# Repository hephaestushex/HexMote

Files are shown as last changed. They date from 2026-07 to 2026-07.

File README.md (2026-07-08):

# HexMote
A wireless game controller with a built in IMU, allowing for motion controlled games. Uses the nRF52840 SuperMini and the ICM-20948 for motion controls.

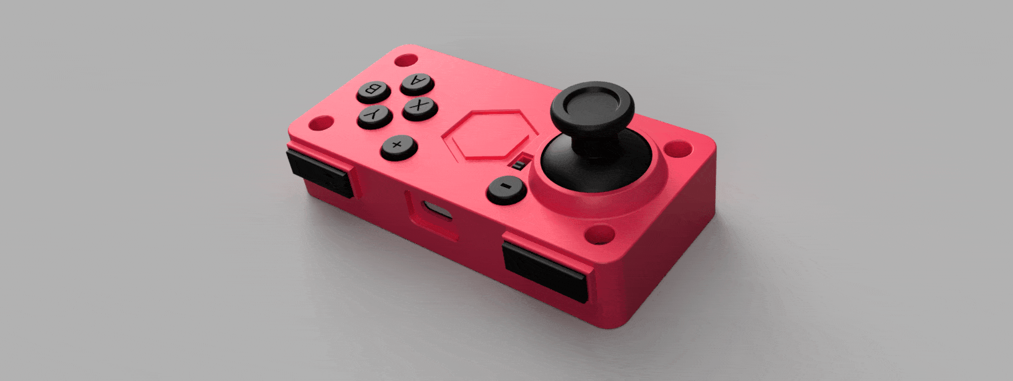
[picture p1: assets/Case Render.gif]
Animated Gif of HexMote, red


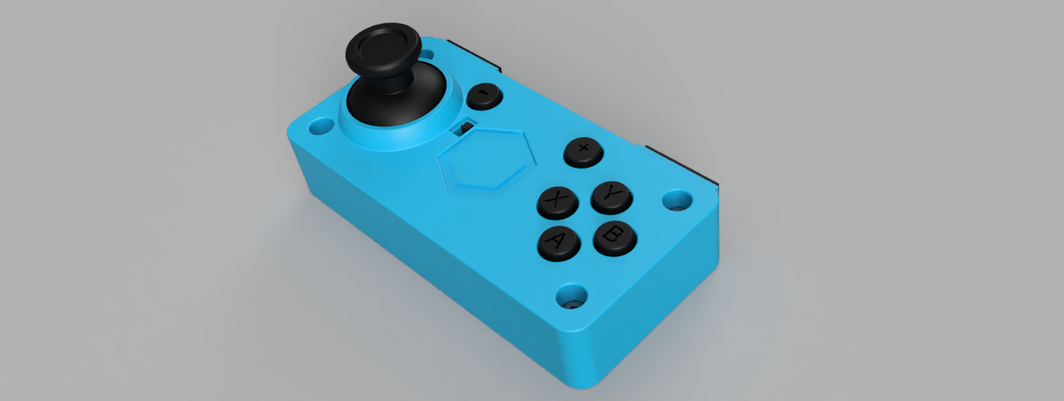
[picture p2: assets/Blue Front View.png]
Render of HexMote, Front, blue


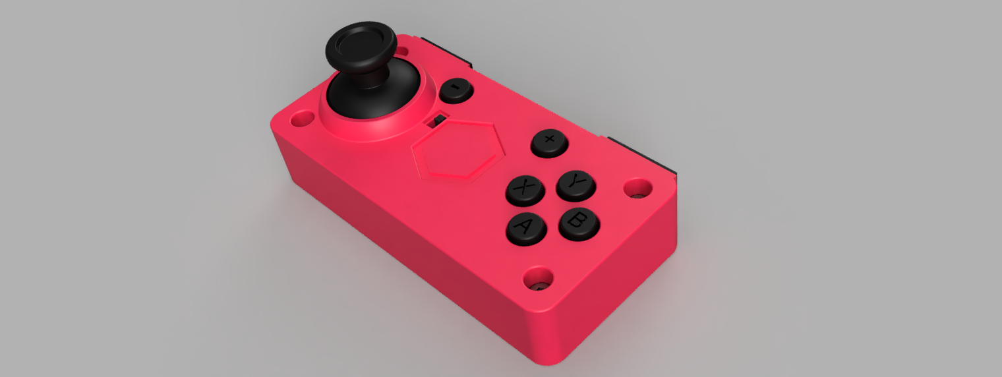
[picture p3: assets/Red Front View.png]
Render of HexMote, Front, red


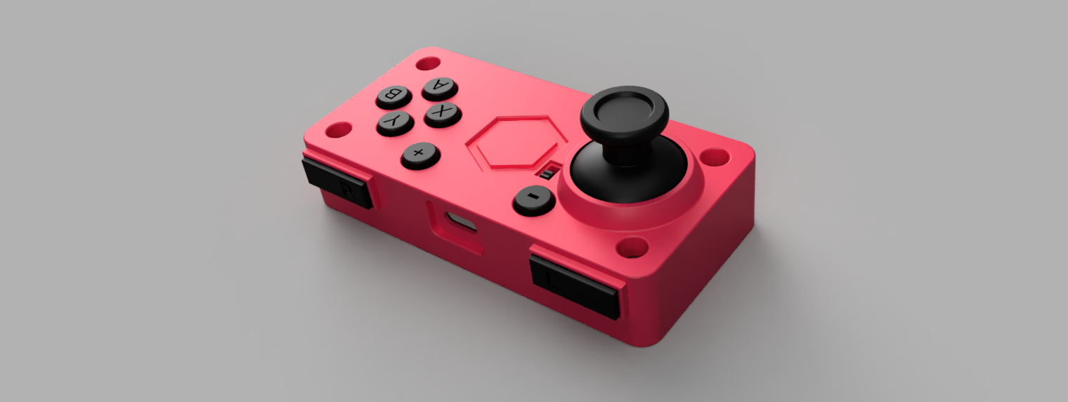
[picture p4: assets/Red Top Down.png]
Render of HexMote, Top Down, red


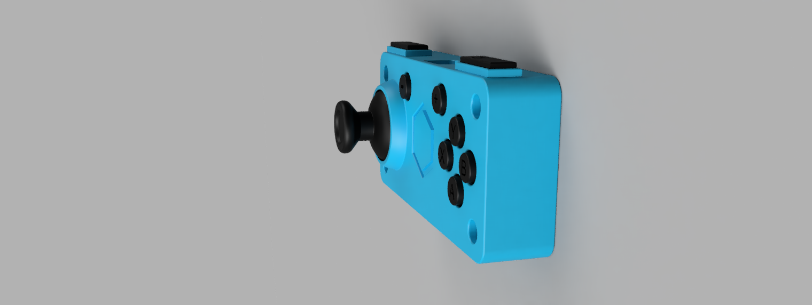
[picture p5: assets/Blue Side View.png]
Render of HexMote, Side, blue


# Inspiration
Recently, I started playing Mario Kart with my sister, but unfortunately for her, she's not too good at video games. The controllers I got, while having hall effect joysticks, lacked motion controls, so my poor sister struggled to steer with the tiny joystick, while turning the controller to no avail. So, I decided to make a Wii-mote-esque controller that would improve the usage while playing motion controlled games. That led birth to the HexMote, a wireless game controller built solely to improve less video-game inclined people.

# Schematic + PCB



Gerbers can be found in pcb/production



The schematic initially used a switch matrix, but falling back to direct pins proved better for pcb traces.







The PCB is 90x40mm, and has surfacemounted THT components through plugging holes with solder, and THT buttons and joysticks

# CAD

The case is split up into 3 parts, one of the top shell, one of the bottom shell, and one of the buttons all together





The PCB mounts on printed standoffs with heatset inserts placed within them, and the m3x6 screws directly into the top shell, through the pcb, and into the insert

# Firmware

The firmware for the hexmote is coded with Arduino, and uses several libraries to allow for BLE communication.

Unfortunately, there are no ways of directly parsing the gyro data within a game, so this requires a Cemuhook DSU script, which is included in the repo. Joystick and buttons work as normal however.

DISCLAIMER: As of right now, the code is AI generated and has not been tested on a physical product. Firmware will be updated and fixed once the HexMote has been built.

# BOM

| Item Name | Qty | Price (total) (USD) | Item link | Notes |
|---|---|---|---|---|
| nRF52840 ProMicro | 1 | $0.99 | [Link](https://www.aliexpress.com/item/1005007383270623.html) | Any nice!nano compatible board should work, check pcb footprint though |
| ICM-20948 Breakout Board | 1 | $4.20 | [Link](https://www.aliexpress.com/item/1005009307235033.html) | You can get a different IMU, but you have to code the sensor fusion code yourself |
| Right Angle Buttons | 2 | $0.99 | [Link](https://www.aliexpress.com/item/1005010093330224.html) | Make sure you get the right length (6x6x7) |
| JST-PH Connector | 1 | $0.99 | [Link](https://www.aliexpress.com/item/1005008970428474.html) | Make sure you get the right connector (right angle) |
| ALPS RKJXV Joystick | 1 | $0.99 | [Link](https://www.aliexpress.com/item/1005009112250803.html) | Make sure you get the PS4 style joystick |
| Soft Tactile Pushbutton | 8 | $0.99 | [Link](https://www.aliexpress.com/item/1005004588874318.html) | Do not substitute for regular clicky buttons, they are not the same footprint |
| M3x5x4 Inserts | 4 | $0.99 | [Link](https://www.aliexpress.com/item/1005011959188413.html) | Ships as 100 |
| M3x6 screws | 4 | $0.99 | [Link](https://www.aliexpress.com/item/32794842281.html) | Ships as 100 |
| 3.7v 500 mah lipo | 1 | $0.99 | [Link](https://www.aliexpress.com/item/1005001485127987) | Really anything works here so long as it meets the 5mm thick, up to 35mm by 80mm dimension requirement and has a jst ph 2.0 connector |
| PCB | 1 | $3.50 | [Link](https://github.com/hephaestushex/HexMote/blob/2a16dff57269423145945d0d09d0ee5307a6468b/pcb/production/hexmote_pcb.zip) | Link is to gerber files, JLC ships the total for 3.50 to Canada |
| Case | 1 | $1.00 | [Link](https://github.com/hephaestushex/HexMote/blob/d6d5b4342bca9d7315f2470e53cb6bb6a80dd431/cad/3d%20print.3mf) | Price differs based on filament. Bambu Lab PLA Matte is used here |
| **Total Price (USD):** | | **$16.62** | | |

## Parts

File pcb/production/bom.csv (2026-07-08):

Designator | Footprint | Quantity | Value | LCSC Part #
J2 | JST_PH_S2B-PH-K_1x02_P2.00mm_Horizontal | 1 | LiPo Cell
J3 | ICM-20498_Board | 1 | Conn_01x10_Pin
SW1, SW2, SW3, SW4, SW5, SW6 | Soft_Tactile_Button_6.00x4.5mm | 6 | SW_Push
SW10 | SW_Slide_SPDT_Straight_CK_OS102011MS2Q | 1 | SW_SPDT
SW7, SW8 | SW_Tactile_SPST_Angled_PTS645Vx83-2LFS | 2 | SW_Push
U2 | PS4_joystick | 1 | Joystick

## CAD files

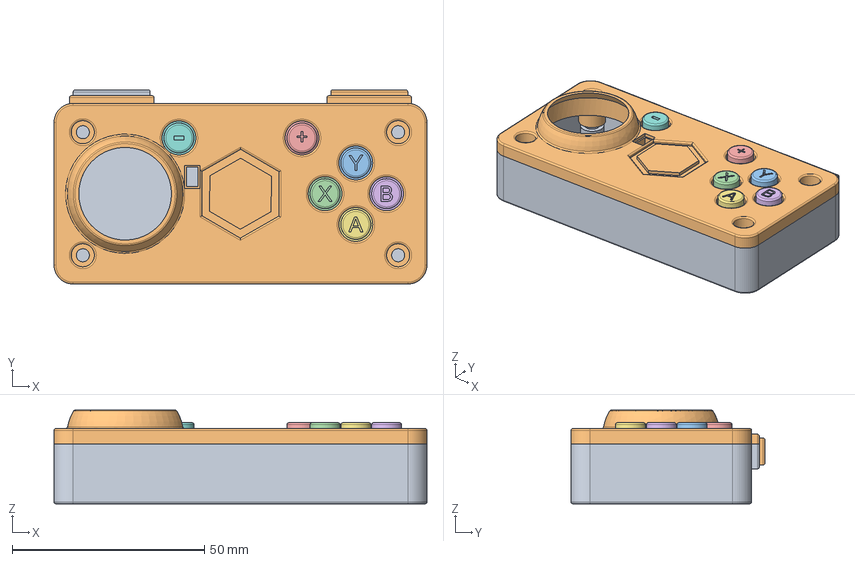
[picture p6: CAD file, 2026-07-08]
cad/Full Assembly.step
97.0 x 50.5 x 24.4 mm

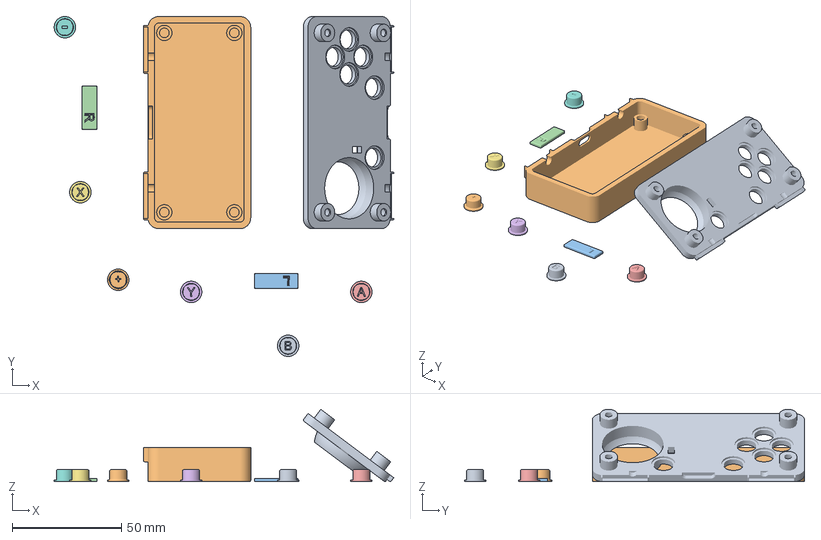
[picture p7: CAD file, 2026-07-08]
cad/3d print.3mf
155.3 x 155.4 x 33.1 mm
Top Shell.step
Bottom Shell.step
Case v36_7
Case v36_8
Case v36_5
Case v36_1
Case v36_2
Case v36_6
Case v36_4
Case v36_3

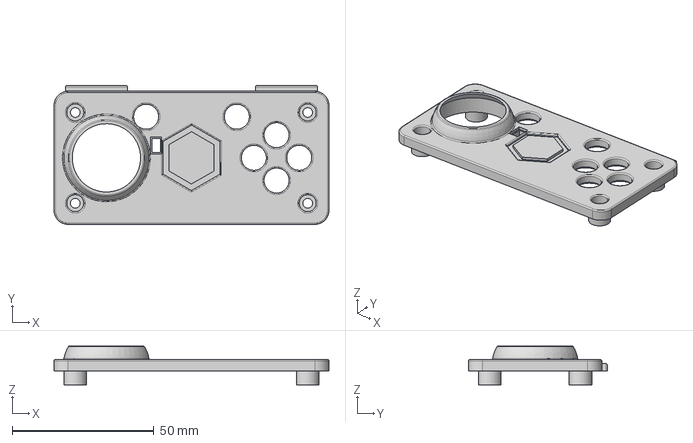
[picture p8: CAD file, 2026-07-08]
cad/Top Shell.step
97.0 x 49.0 x 13.8 mm

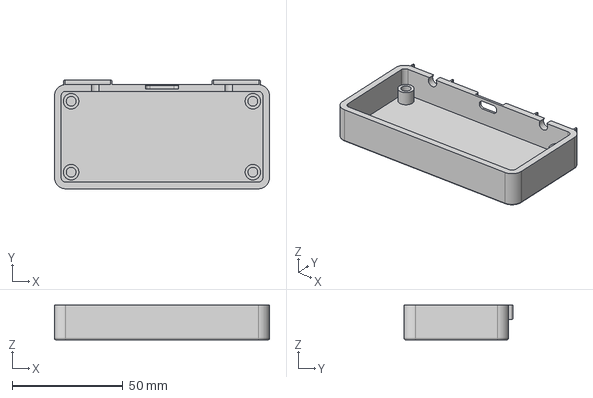
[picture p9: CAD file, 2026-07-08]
cad/Bottom Shell.step
97.0 x 49.0 x 15.6 mm

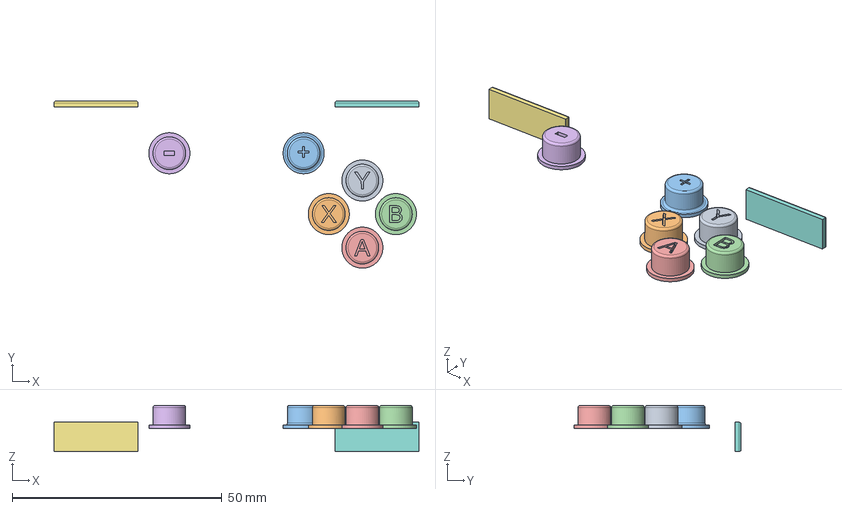
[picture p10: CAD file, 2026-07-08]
cad/Buttons.step
87.0 x 39.9 x 11.0 mm

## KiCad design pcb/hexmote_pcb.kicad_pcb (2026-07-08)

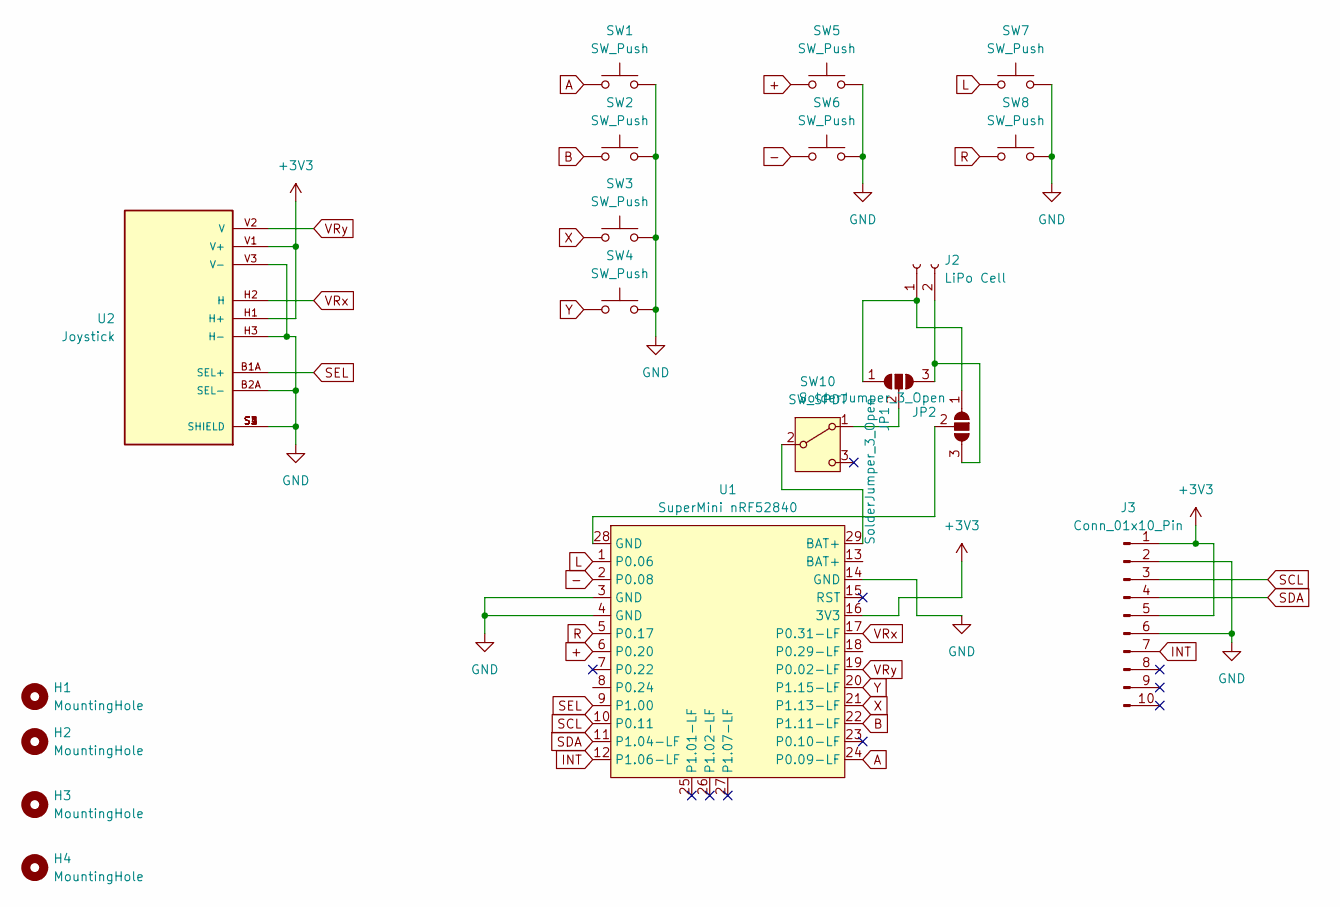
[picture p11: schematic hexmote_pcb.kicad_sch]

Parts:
H1, H2, H3, H4: MountingHole; MountingHole_3.2mm_M3
J2: LiPo Cell; JST_PH_S2B-PH-K_1x02_P2.00mm_Horizontal
J3: Conn_01x10_Pin; ICM-20498_Board
JP1, JP2: SolderJumper_3_Open; SolderJumper-3_P1.3mm_Open_Pad1.0x1.5mm_NumberLabels
SW1, SW2, SW3, SW4, SW5, SW6: SW_Push; Soft_Tactile_Button_6.00x4.5mm
SW7, SW8: SW_Push; SW_Tactile_SPST_Angled_PTS645Vx83-2LFS
SW10: SW_SPDT; SW_Slide_SPDT_Straight_CK_OS102011MS2Q
U1: SuperMini nRF52840; SuperMini NRF52840
U2: Joystick; PS4_joystick; PARTREV N/A

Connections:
+: SW5.1, U1.6 (P0.20)
+3V3: J3.1, J3.5, U1.16 (3V3), U2.H1 (H+), U2.V1 (V+)
-: SW6.1, U1.2 (P0.08)
A: SW1.1, U1.24 (P0.09-LF)
B: SW2.1, U1.22 (P1.11-LF)
GND: J3.2, J3.6, SW1.2, SW2.2, SW3.2, SW4.2, SW5.2, SW6.2, SW7.2, SW8.2, U1.3 (GND), U1.4 (GND), U1.14 (GND), U2.B2A (SEL-), U2.H3 (H-), U2.S1 (SHIELD), U2.S2 (SHIELD), U2.S3 (SHIELD), U2.S4 (SHIELD), U2.V3 (V-)
INT: J3.7, U1.12 (P1.06-LF)
L: SW7.1, U1.1 (P0.06)
unnamed: J2.1, JP1.1 (A), JP2.1 (A)
unnamed: J2.2, JP1.3 (B), JP2.3 (B)
unnamed: JP1.2 (C), SW10.1 (A)
unnamed: JP2.2 (C), U1.28 (GND)
unnamed: SW10.2 (B), U1.29 (BAT+)
R: SW8.1, U1.5 (P0.17)
SCL: J3.3, U1.10 (P0.11)
SDA: J3.4, U1.11 (P1.04-LF)
SEL: U1.9 (P1.00), U2.B1A (SEL+)
VRx: U1.17 (P0.31-LF), U2.H2 (H)
VRy: U1.19 (P0.02-LF), U2.V2 (V)
X: SW3.1, U1.21 (P1.13-LF)
Y: SW4.1, U1.20 (P1.15-LF)

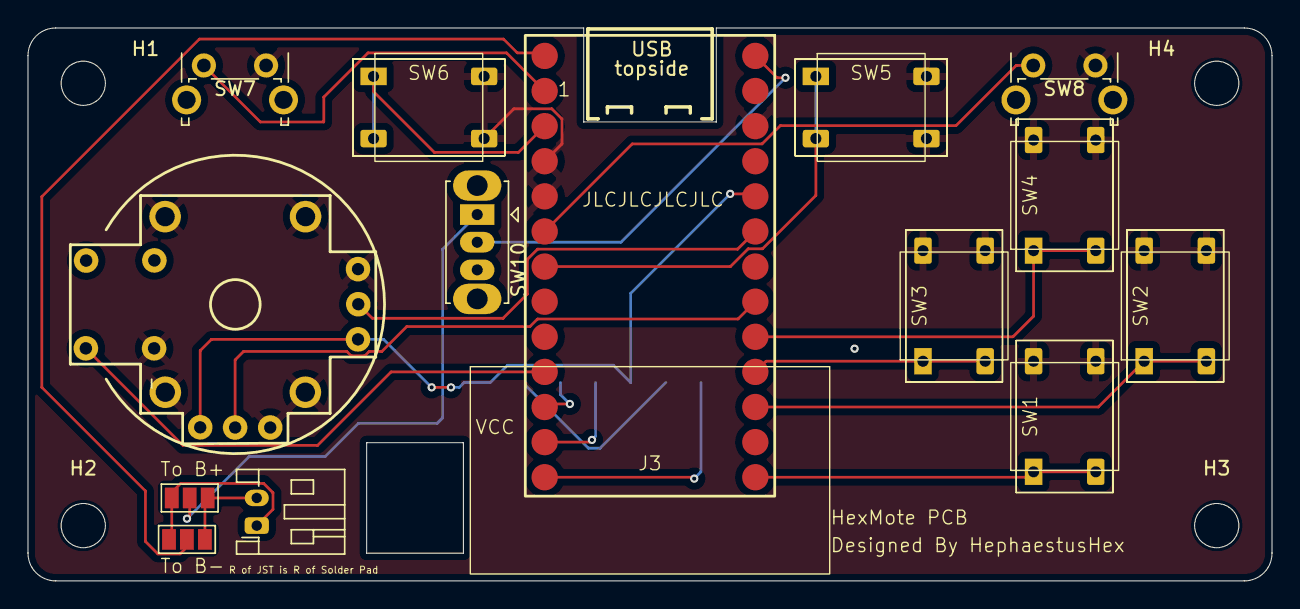
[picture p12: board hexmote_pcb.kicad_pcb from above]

Board: 2 copper layers, 90.0 x 40.0 mm, 19 parts (0 on the bottom side), 21 nets.

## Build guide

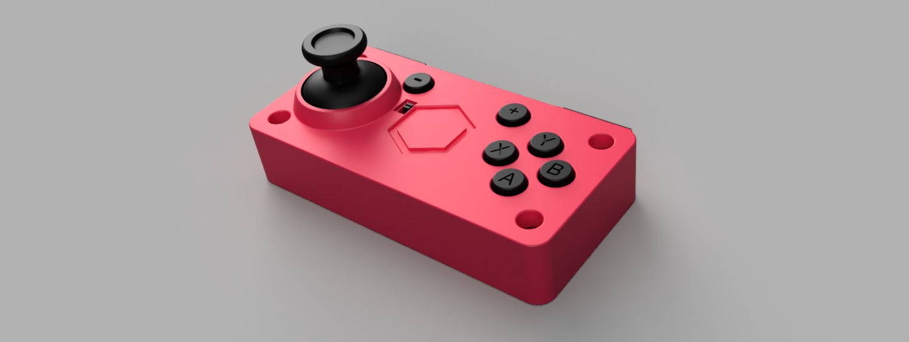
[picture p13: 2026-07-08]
assets/Case_(Assembly)_2026-Jul-08_06-05-27PM-000_CustomizedView10271644335_zip/frame.3.png

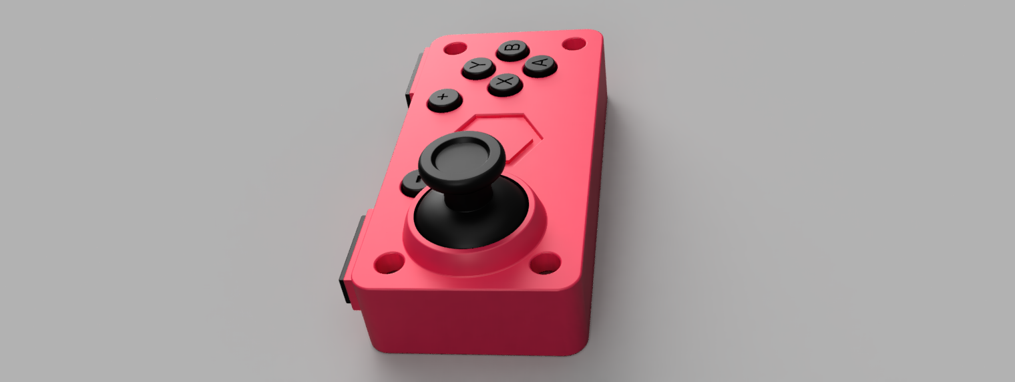
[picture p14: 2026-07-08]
assets/Case_(Assembly)_2026-Jul-08_06-05-27PM-000_CustomizedView10271644335_zip/frame.5.png

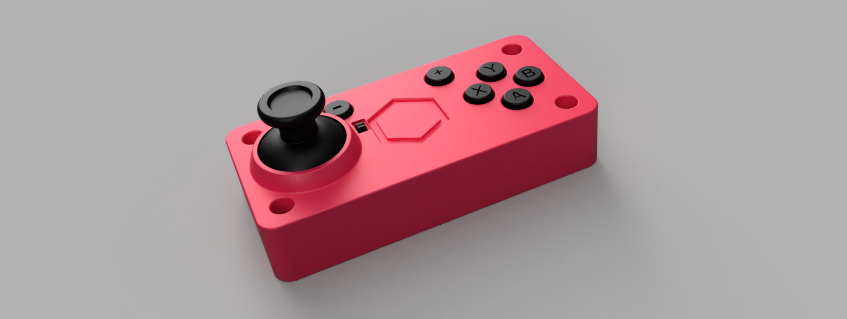
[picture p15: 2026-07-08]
assets/Case_(Assembly)_2026-Jul-08_06-05-27PM-000_CustomizedView10271644335_zip/frame.4.png

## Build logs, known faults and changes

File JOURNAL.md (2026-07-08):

# JOURNAL

# Total time: 14h

# July 6th

*Note: I was too locked in to take screenshots, but I did record through lapse*

[Recording 1](https://lapse.hackclub.com/timelapse/f-8UHHHKltJs)
[Recording 2](https://lapse.hackclub.com/timelapse/fGfNaLuvpSXH)

## 6h

I had a vague idea of what I was building before I went into this, so here's a quick explanation:

 - Wireless Game Controller with Motion Controls
 - uses nRF52840 for power efficient BLE (seeed studio xiao nrf52840 board)
 - Uses 18650 cell
 - has low profile joystick, 4 a/b/x/y buttons, +/-, l/r
 - has an IMU for motion controls (generic arduino module?)

From here, I just went on a long speedrun of pcb design. It mostly went as you expected (place symbols, wire it up, assign footprints, arrange, wire, done!), but I ran into several hurdles along the way. I'll explain each hurdle in detail

### Parts Selection

There wasn't enough pins on the XIAO, so I opted for the nRF52840 SuperMini board. It's a clone of the nice!nano, but its readily available on aliexpress

The Wii uses an IR sensor for detecting heading, so I needed a board with heading detection, so no mpu6050. I found the ICM-20948, which has 9 DOF (3x accelerometer, 3x gyro, 3x magnetometer)

The 18650 is too big and would make the overall controller large and heavy, so I switched to a 3.7v LiPo Battery.

None of the low-profile joysticks seem to have a basic pinout on aliexpress, so I opted for a ALPS Joystick that you would find in a PS4/XBOX controller. It should be smaller than the arduino joystick modules. At least it will be mounted directly to the pcb to save on vertical clearance. 

The rest of the parts selection was easy, simply searching on aliexpress for something that'll work.

### PCB Footprints/Schematics

There aren't any readily available footprints/schematics for the joystick, so I had to scour the internet for one that'll work with the joystick. I found this module from [github](https://github.com/little-scale/PS4_joystick_footprint), and the person also made it in real life so I trusted it would fit.





I didn't bother with finding footprints for the squishy buttons (IMO better than clicky for game controllers), so I made a footprint based on the aliexpress diagram.



As for the IMU, I had to create a footprint to ensure my parts won't intrude on it. I also realized I was looking at another module halfway into designing the PCB.



### IMU Mounting

I can't place the imu off to the side for two reasons. A, it would take too much room, and B, it wouldn't record motions properly

I chose to mount it on the back to solve these problems, but the long headers would clash with the MCU. I know of a method to solder tht boards smd style, by plugging the holes with solder, so I changed the THT pads to SMD pads for it.

I also found out that the MCU might mess with the magnetometer, so I placed it down the PCB to avoid it



### To make a matrix, or not to make a matrix, that is the question

I initially used a switch matrix to save on pins, but the diodes couldn't be placed nicely without taking more space. The wiring turned out horrible with way too much vias. It could also be because I didn't route traces properly, but direct pins plus a ground plane made the wiring way cleaner.



### Layout

The PCB layout was tricky, as I was rusty, plus there's a lot more components. In the end, I managed to get it squished under 90mm by 40mm, so $2 dollar pcbs for JLC!

### nRF52840 internal multiplexer my goat

I would have been fried if the nRF52840 kept its pins static. Luckily, almost every pin can be used for everything, so I could select pins based on which was closer and cleaner.

### Conclusion

Well I finished the PCB, so heres a few pictures of it.







Oh I did run into a couple of DRC errors. It had to do with the ground plane, but all I had to do is move a couple of traces around.

Also Claude is the GOAT of AI, it can actually do stuff without hallucinating (chatgpt), or run into safety filter every 5 seconds (gemini), and it even has a better toolbox! Would not have done it this fast without claude.

# July 7th-8th (not really, i just pulled an all nighter)
## 7h (this much screen time can't be good on my eyes)

[Timelapse](https://lapse.hackclub.com/timelapse/uQqbto0yiFiv) please look at this as I was too locked in to take screenshots apart for a few.

So I didn't do any CAD yet, so I cracked down on it and started in the evening, and stayed up until 4:30? (its 4:20 as of writing this)

First issue was I was rusty, so apart of creating the base and sticking a couple of pegs on it, I was stuck on figuring out how to create the holes properly



I ran into a lot of unconstrained lines, but after a while I gave up, considering it doesn't necessarily break anything at this scale (note to self: take an actual CAD course). That doesn't mean I didn't try, I just didn't try too hard to fix the annoying constraints (text boxes) 

Another annoying thing is finding CAD reliably without making 5000 accounts. I did make a handheld a year back, so I lowkey just stole the cad files from that since I couldn't find it today. It's also today I resigned myself to the fact that I will not get this in time for Outpost (sadge) but redesigning it to house more expensive parts that might arrive on time didn't make sense. Plus no one sells lipos and nice!nanos for a decent rate in Canada.

It also occured to me that I didn't account for lipos being wired wrong, so I added solder pads to fix that. It did appear that most had + on the right, but I figured this would be better. That also led into a rabbit hole of finding lipos that would work, but after chatting with Claude (goat btw), I figured anything about 500mah that was legit would work. I also made sure to design the case to fit the lipo (anything 5mm thick, within 40x90mm). In the end, I just slapped some aliexpress links there that would work.

CAD was not fun, so here are some highlights (or lack thereof):

### Creating holes

I had no idea how to make the holes in the right place, so I bounced back and forth between the PCB and Fusion measuring out dimensions and seeing if they worked. I realized too late I can import an stl into a part studio. After a lot of trial and error, I created the holes in the right place for the shoulder buttons and the USB-C slot. This time, I actually spent time and made the hole look pretty, and I think it was worth it!



### Create elevated portion for Joystick

So like I said, I don't really know CAD too well, just enough to trudge along. So when it came time for me to do something other than a sketch and extrude, I blanked out. After some searching up, I learned how to create an offset plane. From there, it wasn't too bad, just a matter of creating curves and revolving them.



### How to fit everything together without making it too thick

So i really should have went into this with a written out plan. I figured I could have two circles of inserts, one for the pcb, and one for the case, but that was too thick, so I reduced it to one by sandwiching the whole case+pcb under one screw and insert.



### Buttons

This actually wasn't hard as it was tedious, creating circles and making sure the buttons remained separate from the case, which happened a few times





So that's an issue, but I figured that it shouldn't matter too much, as no one is necessarily needing to press - while controlling the joystick in the horizontal position, and in the vertical position, it can be held easily with the right hand or dual handed like a sword.

### Text
Text is a pain to constrain, I'll leave it at that. I didn't even bother doing it properly

### Shoulder Buttons

Initially, I planned to leave the shoulder buttons alone, but I ended up designing them



So I decided to design shoulder buttons for two reasons:
-  They're probably annoying to reach and press
-  they kind of look like nipples



I had to make sure it doesn't look too bad, so I designed the guard rails as well.

### Rendering
I wanted to render it, but apparently, being linked forces all of the objects to stay the same colour, but fusion removed the break link feature for some reason, causing me to crash out for 10 minutes. (claude my goat for helping me break the link through another menu). Eventually, I got it, set it to totally not important colours, and rendered them!

Red Top Down
Red Front View
Blue Side View
Blue Front View

### Conclusion

It is now 5 AM, and I have been up for nearly 23 hours. I doubt I can work on firmware now, so I'll come back to it tomorrow. No actually today.

Overall a pretty productive day(s) I would say.

# July 8th (for real this time)

## 1h

[Lapse](https://lapse.hackclub.com/timelapse/Px4isJaHPv2T)

So in my sleep deprivedness, I forgot to make a hole for the switch, which I promptly did, followed by the restructuring of every CAD file + render. I also made a nice gif for rotating the HexMote around.

As for the firmware, it turns out I should have done more research, as BLE doesn't natively send gyro data, so the nRF52840 doesn't really work for this. However, there is a fix, by sending raw gyro data over and using a DSU server for gyro data, which works for the emulators I need anyway (raw ble doesn't really work). Claude was surprisingly helpful, and made the code that works (with no hardware errors at least) on the second try.

From there, all I'm doing is cleaning this project up and submitting it, which shouldn't take too long as I have been doing it along the way

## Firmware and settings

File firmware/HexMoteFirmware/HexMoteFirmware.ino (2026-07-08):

/*
 * HexMote Firmware -- v0.4
 * SuperMini nRF52840 + ICM-20948 + ALPS joystick
 *
 * v0.4 switches to the official Adafruit BLEHidGamepad class instead of a
 * hand-rolled BLEHidGeneric descriptor -- caught real compile errors in the
 * v0.3 approach (setReportLen/setReportDescriptor signatures were wrong).
 * This is now built on the library's own tested gamepad implementation.
 *
 * v0.3 added Serial debug output (gated by DEBUG_SERIAL below) so you can
 * verify buttons, joystick, and IMU are alive over USB before trusting the
 * BLE side. Flip DEBUG_SERIAL to 0 once everything checks out.
 *
 * Architecture (locked in):
 *   - Standard BLE HID gamepad (buttons + stick) -> works natively in Steam
 *     Input, Windows, Linux, anywhere -- zero extra software required.
 *   - Separate custom BLE GATT service streaming raw accel+gyro -> read by
 *     your Steam Deck DSU companion app, which relays it to Dolphin/Cemu/
 *     Yuzu as a standard DSU (cemuhook) motion source.
 *   - Steam Input gyro (native, non-emulator games) is NOT covered by this
 *     path -- that's a separate DS4-identity-spoof problem, not built here.
 *
 * Pin mapping (from hexmote_pcb.kicad_sch):
 *   A=P0.09  B=P1.11  X=P1.13  Y=P1.15
 *   L=P0.06  R=P0.17  +=P0.20  -=P0.08
 *   Joystick click (SEL) = P1.00
 *   Joystick X (AIN7) = P0.31   Joystick Y (AIN0) = P0.02
 *   I2C: SCL=P0.11  SDA=P1.04  IMU INT=P1.06 (unused, poll-only for now)
 *
 * Charging: fully hardware (onboard SuperMini charge IC + SW10 power
 * switch). No firmware involvement.
 *
 * !! IMPORTANT: the motion GATT UUIDs and 12-byte payload layout below are
 * placeholders I defined myself. I don't have visibility into what your
 * specific Steam Deck DSU companion app expects on the BLE side -- you'll
 * need to check its docs/source and either match its expected UUID/format,
 * or adjust the app's parsing to match what's below. Flagging this clearly
 * so it's not a silent assumption.
 *
 * Compile-UNTESTED (no nRF52 toolchain in this sandbox). Pin assignments
 * verified against the schematic; BLE/IMU boilerplate is standard-pattern
 * but give it a real smoke test before trusting it.
 */

#include <bluefruit.h>
#include <Wire.h>
#include <nrf_gpio.h>
#include <nrf_saadc.h>

// ---------------- Debug scaffolding ----------------
// Flip to 0 once everything's verified -- Serial prints cost a little loop
// time and there's no reason to keep them running once BLE is trusted.
#define DEBUG_SERIAL 1

#if DEBUG_SERIAL
  #define DBG_BEGIN(baud)   Serial.begin(baud)
  #define DBG_PRINT(...)    Serial.print(__VA_ARGS__)
  #define DBG_PRINTLN(...)  Serial.println(__VA_ARGS__)
#else
  #define DBG_BEGIN(baud)
  #define DBG_PRINT(...)
  #define DBG_PRINTLN(...)
#endif

// ---------------- Pin definitions (raw GPIO numbers) ----------------
#define PIN_A     NRF_GPIO_PIN_MAP(0, 9)
#define PIN_B     NRF_GPIO_PIN_MAP(1, 11)
#define PIN_X     NRF_GPIO_PIN_MAP(1, 13)
#define PIN_Y     NRF_GPIO_PIN_MAP(1, 15)
#define PIN_L     NRF_GPIO_PIN_MAP(0, 6)
#define PIN_R     NRF_GPIO_PIN_MAP(0, 17)
#define PIN_PLUS  NRF_GPIO_PIN_MAP(0, 20)
#define PIN_MINUS NRF_GPIO_PIN_MAP(0, 8)
#define PIN_SEL   NRF_GPIO_PIN_MAP(1, 0)   // joystick click

#define PIN_SDA   NRF_GPIO_PIN_MAP(1, 4)
#define PIN_SCL   NRF_GPIO_PIN_MAP(0, 11)

#define AIN_JOY_X  7   // P0.31
#define AIN_JOY_Y  0   // P0.02

// ---------------- ICM-20948 register map (minimal subset) ----------------
#define ICM_ADDR        0x69   // change to 0x68 if your breakout pulls AD0 low
#define REG_BANK_SEL    0x7F
#define B0_WHO_AM_I     0x00
#define B0_PWR_MGMT_1   0x06
#define B0_ACCEL_XOUT_H 0x2D
#define B0_GYRO_XOUT_H  0x33
#define B2_GYRO_CFG_1   0x01
#define B2_ACCEL_CFG    0x14

bool icmSelectBank(uint8_t bank) {
  Wire.beginTransmission(ICM_ADDR);
  Wire.write(REG_BANK_SEL);
  Wire.write(bank << 4);
  return Wire.endTransmission() == 0;
}

bool icmWriteReg(uint8_t bank, uint8_t reg, uint8_t val) {
  icmSelectBank(bank);
  Wire.beginTransmission(ICM_ADDR);
  Wire.write(reg);
  Wire.write(val);
  return Wire.endTransmission() == 0;
}

bool icmReadRegs(uint8_t bank, uint8_t reg, uint8_t *buf, uint8_t len) {
  icmSelectBank(bank);
  Wire.beginTransmission(ICM_ADDR);
  Wire.write(reg);
  if (Wire.endTransmission(false) != 0) return false;
  Wire.requestFrom(ICM_ADDR, (int)len);
  for (uint8_t i = 0; i < len && Wire.available(); i++) buf[i] = Wire.read();
  return true;
}

uint8_t icmLastWhoAmI = 0; // stashed for debug printing after icmInit()

bool icmInit() {
  uint8_t who = 0;
  icmReadRegs(0, B0_WHO_AM_I, &who, 1);
  icmLastWhoAmI = who;
  if (who != 0xEA) return false; // wrong address or not detected -- check ICM_ADDR/wiring

  icmWriteReg(0, B0_PWR_MGMT_1, 0x01);   // wake, auto clock select
  delay(10);
  icmWriteReg(2, B2_GYRO_CFG_1, 0x00);   // +/-250 dps, no DLPF (default)
  icmWriteReg(2, B2_ACCEL_CFG, 0x00);    // +/-2g, no DLPF (default)
  return true;
}

void icmReadMotion(int16_t &ax, int16_t &ay, int16_t &az,
                    int16_t &gx, int16_t &gy, int16_t &gz) {
  uint8_t raw[6];
  icmReadRegs(0, B0_ACCEL_XOUT_H, raw, 6);
  ax = (int16_t)((raw[0] << 8) | raw[1]);
  ay = (int16_t)((raw[2] << 8) | raw[3]);
  az = (int16_t)((raw[4] << 8) | raw[5]);

  icmReadRegs(0, B0_GYRO_XOUT_H, raw, 6);
  gx = (int16_t)((raw[0] << 8) | raw[1]);
  gy = (int16_t)((raw[2] << 8) | raw[3]);
  gz = (int16_t)((raw[4] << 8) | raw[5]);
}

// ---------------- Minimal blocking SAADC read ----------------
uint16_t analogReadRaw(uint8_t ain) {
  NRF_SAADC->ENABLE = 1;
  NRF_SAADC->RESOLUTION = SAADC_RESOLUTION_VAL_10bit;

  NRF_SAADC->CH[0].CONFIG =
      (SAADC_CH_CONFIG_GAIN_Gain1_4 << SAADC_CH_CONFIG_GAIN_Pos) |
      (SAADC_CH_CONFIG_REFSEL_Internal << SAADC_CH_CONFIG_REFSEL_Pos) |
      (SAADC_CH_CONFIG_TACQ_20us << SAADC_CH_CONFIG_TACQ_Pos) |
      (SAADC_CH_CONFIG_MODE_SE << SAADC_CH_CONFIG_MODE_Pos);
  NRF_SAADC->CH[0].PSELP = ain + 1; // AIN0..AIN7 map to PSELP 1..8
  NRF_SAADC->CH[0].PSELN = SAADC_CH_PSELN_PSELN_NC;

  static int16_t result;
  NRF_SAADC->RESULT.PTR = (uint32_t)&result;
  NRF_SAADC->RESULT.MAXCNT = 1;

  NRF_SAADC->TASKS_START = 1;
  while (!NRF_SAADC->EVENTS_STARTED);
  NRF_SAADC->EVENTS_STARTED = 0;

  NRF_SAADC->TASKS_SAMPLE = 1;
  while (!NRF_SAADC->EVENTS_END);
  NRF_SAADC->EVENTS_END = 0;

  NRF_SAADC->TASKS_STOP = 1;
  while (!NRF_SAADC->EVENTS_STOPPED);
  NRF_SAADC->EVENTS_STOPPED = 0;

  NRF_SAADC->ENABLE = 0;
  if (result < 0) result = 0;
  return (uint16_t)result; // 0-1023 (10-bit)
}

// ---------------- BLE HID gamepad (official Adafruit BLEHidGamepad class) ----------------
// Using the library's own gamepad implementation instead of a hand-rolled
// custom HID descriptor -- far less surface area for the kind of API
// mismatches that bit us with the earlier BLEHidGeneric approach.
BLEDis bledis;
BLEHidGamepad blegamepad;
hid_gamepad_report_t gp; // defined in hid.h via Adafruit_TinyUSB, pulled in by bluefruit.h

// Button bit assignments within gp.buttons (bitmask, up to 32 buttons supported)
#define BTN_A     (1UL << 0)
#define BTN_B     (1UL << 1)
#define BTN_X     (1UL << 2)
#define BTN_Y     (1UL << 3)
#define BTN_L     (1UL << 4)
#define BTN_R     (1UL << 5)
#define BTN_PLUS  (1UL << 6)
#define BTN_MINUS (1UL << 7)
#define BTN_SEL   (1UL << 8)

// ---------------- Custom motion GATT service ----------------
// PLACEHOLDER UUIDs -- verify/match against your DSU companion app.
const uint8_t MOTION_SVC_UUID[16]    = {0x9E,0x5D,0x80,0xE0,0x25,0x08,0x4B,0x92,0x8B,0x2F,0x4B,0x1C,0x01,0x00,0x0F,0xA0};
const uint8_t MOTION_CHAR_UUID[16]   = {0x9E,0x5D,0x80,0xE0,0x25,0x08,0x4B,0x92,0x8B,0x2F,0x4B,0x1C,0x02,0x00,0x0F,0xA0};

BLEService        motionService(MOTION_SVC_UUID);
BLECharacteristic motionChar(MOTION_CHAR_UUID);

#pragma pack(push, 1)
struct HexMotionPacket {
  int16_t ax, ay, az;   // raw accel, +/-2g range, LSB per ICM-20948 datasheet
  int16_t gx, gy, gz;   // raw gyro, +/-250 dps range, LSB per ICM-20948 datasheet
};
#pragma pack(pop)

HexMotionPacket motionPacket;

void setupMotionService() {
  motionService.begin();

  motionChar.setProperties(CHR_PROPS_NOTIFY | CHR_PROPS_READ);
  motionChar.setPermission(SECMODE_OPEN, SECMODE_NO_ACCESS);
  motionChar.setFixedLen(sizeof(HexMotionPacket));
  motionChar.begin();
}

// ---------------- BLE setup ----------------
void setupBLE() {
  Bluefruit.begin();
  Bluefruit.setTxPower(4);
  Bluefruit.setName("HexMote");

  bledis.setManufacturer("hephaestushex");
  bledis.setModel("HexMote v0.4");
  bledis.begin();

  blegamepad.begin();

  setupMotionService();

  Bluefruit.Advertising.addFlags(BLE_GAP_ADV_FLAGS_LE_ONLY_GENERAL_DISC_MODE);
  Bluefruit.Advertising.addAppearance(BLE_APPEARANCE_HID_GAMEPAD);
  Bluefruit.Advertising.addService(blegamepad);
  Bluefruit.Advertising.addService(motionService);
  Bluefruit.Advertising.addName();
  Bluefruit.Advertising.restartOnDisconnect(true);
  Bluefruit.Advertising.setInterval(32, 244);
  Bluefruit.Advertising.setFastTimeout(30);
  Bluefruit.Advertising.start(0);
}

// ---------------- Buttons ----------------
void setupButtons() {
  int pins[] = {PIN_A, PIN_B, PIN_X, PIN_Y, PIN_L, PIN_R, PIN_PLUS, PIN_MINUS, PIN_SEL};
  for (int p : pins) nrf_gpio_cfg_input(p, NRF_GPIO_PIN_PULLUP);
}

uint32_t readButtons() {
  uint32_t b = 0;
  if (!nrf_gpio_pin_read(PIN_A))     b |= BTN_A;
  if (!nrf_gpio_pin_read(PIN_B))     b |= BTN_B;
  if (!nrf_gpio_pin_read(PIN_X))     b |= BTN_X;
  if (!nrf_gpio_pin_read(PIN_Y))     b |= BTN_Y;
  if (!nrf_gpio_pin_read(PIN_L))     b |= BTN_L;
  if (!nrf_gpio_pin_read(PIN_R))     b |= BTN_R;
  if (!nrf_gpio_pin_read(PIN_PLUS))  b |= BTN_PLUS;
  if (!nrf_gpio_pin_read(PIN_MINUS)) b |= BTN_MINUS;
  if (!nrf_gpio_pin_read(PIN_SEL))   b |= BTN_SEL;
  return b;
}

bool icmReady = false;
uint32_t lastMotionMs = 0;
const uint32_t MOTION_INTERVAL_MS = 10; // ~100Hz motion stream

void setup() {
  DBG_BEGIN(115200);
#if DEBUG_SERIAL
  uint32_t serialWaitStart = millis();
  while (!Serial && (millis() - serialWaitStart < 3000)) { /* give USB CDC a few seconds, don't hang forever if no monitor is open */ }
#endif
  DBG_PRINTLN();
  DBG_PRINTLN(F("=== HexMote booting ==="));

  setupButtons();
  DBG_PRINTLN(F("Buttons configured (pull-ups enabled)"));

  Wire.setPins(PIN_SDA, PIN_SCL);
  Wire.begin();
  Wire.setClock(400000);

  icmReady = icmInit(); // false -> motion packet stays zero, check wiring/address
  DBG_PRINT(F("ICM-20948 WHO_AM_I = 0x"));
  DBG_PRINTLN(String(icmLastWhoAmI, HEX));
  DBG_PRINTLN(icmReady ? F("ICM-20948 init OK") : F("ICM-20948 init FAILED -- check I2C wiring/address (try 0x68 if 0x69 fails)"));

  setupBLE();
  DBG_PRINTLN(F("BLE advertising started as 'HexMote'"));
  DBG_PRINTLN(F("=== Setup complete ==="));
}

#if DEBUG_SERIAL
uint32_t lastDebugMs = 0;
const uint32_t DEBUG_INTERVAL_MS = 250; // 4x/sec -- readable without flooding the monitor

void printDebugLine(uint32_t buttons, uint16_t rawX, uint16_t rawY) {
  DBG_PRINT(F("BLE:"));
  DBG_PRINT(Bluefruit.connected() ? F("connected") : F("advertising"));

  DBG_PRINT(F("  buttons:0b"));
  for (int i = 8; i >= 0; i--) DBG_PRINT((buttons >> i) & 1);

  DBG_PRINT(F("  joyX:"));
  DBG_PRINT(rawX);
  DBG_PRINT(F("  joyY:"));
  DBG_PRINT(rawY);

  if (icmReady) {
    DBG_PRINT(F("  accel(ax,ay,az):"));
    DBG_PRINT(motionPacket.ax); DBG_PRINT(F(","));
    DBG_PRINT(motionPacket.ay); DBG_PRINT(F(","));
    DBG_PRINT(motionPacket.az);
    DBG_PRINT(F("  gyro(gx,gy,gz):"));
    DBG_PRINT(motionPacket.gx); DBG_PRINT(F(","));
    DBG_PRINT(motionPacket.gy); DBG_PRINT(F(","));
    DBG_PRINT(motionPacket.gz);
  } else {
    DBG_PRINT(F("  IMU:not detected"));
  }
  DBG_PRINTLN();
}
#endif

void loop() {
  // --- Buttons + joystick read every loop, regardless of BLE state, so ---
  // --- Serial debug output works even before/without a BLE connection. ---
  uint32_t buttons = readButtons();
  uint16_t rawX = analogReadRaw(AIN_JOY_X);
  uint16_t rawY = analogReadRaw(AIN_JOY_Y);

  uint32_t now = millis();

  // --- Motion read: own cadence, independent of connection state ---
  if (now - lastMotionMs >= MOTION_INTERVAL_MS) {
    lastMotionMs = now;
    if (icmReady) {
      icmReadMotion(motionPacket.ax, motionPacket.ay, motionPacket.az,
                    motionPacket.gx, motionPacket.gy, motionPacket.gz);
    }
  }

#if DEBUG_SERIAL
  if (now - lastDebugMs >= DEBUG_INTERVAL_MS) {
    lastDebugMs = now;
    printDebugLine(buttons, rawX, rawY);
  }
#endif

  if (!Bluefruit.connected()) {
    delay(20);
    return;
  }

  // --- Gamepad report: buttons + stick, sent every loop while connected ---
  // hid_gamepad_report_t expects signed -127..127, center 0, per TinyUSB's
  // spec -- convert from the 10-bit 0..1023 ADC reading accordingly.
  gp.x = (int8_t)(((int32_t)rawX - 512) * 127 / 512);
  gp.y = (int8_t)(((int32_t)rawY - 512) * 127 / 512);
  gp.z = 0;
  gp.rz = 0;
  gp.rx = 0;
  gp.ry = 0;
  gp.hat = 0;
  gp.buttons = buttons;
  blegamepad.report(&gp);

  // --- Motion notify: send whatever we most recently read above ---
  if (motionChar.notifyEnabled()) {
    motionChar.notify(&motionPacket, sizeof(motionPacket));
  }

  delay(4); // ~125Hz+ loop rate for button/stick responsiveness
}

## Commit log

2026-07-06 added schematic for hexmote
    [hexmote_pcb.kicad_pcb, hexmote_pcb.kicad_sch]
2026-07-06 fixed joystick button having extra button
    [hexmote_pcb.kicad_sch]
2026-07-06 finished schematic and layed out components
    [hexmote_pcb.kicad_pcb, hexmote_pcb.kicad_sch]
2026-07-07 finished PCB
    [hexmote_pcb.kicad_pcb, hexmote_pcb.kicad_sch]
2026-07-07 Enhance README with project details and design insights
    Expanded the README with detailed project documentation, including parts selection, PCB design challenges, and layout considerations for the HexMote wireless game controller.
2026-07-07 Revise README with project overview and design insights
    Removed outdated project details and added a brief overview of the HexMote game controller design process, including parts selection, PCB design challenges, and layout considerations.
2026-07-07 Add detailed journal entry for July 6th
    Documented the design process and challenges faced while building a wireless game controller with motion controls, including parts selection, PCB design, and layout considerations.
2026-07-07 cleaned up schematic+pcb
    [hexmote_pcb.kicad_sch]
2026-07-07 Expand README with additional project details
    Added sections for inspiration, schematic, PCB, CAD, firmware, and BOM to README.
2026-07-07 added solder jumper to allow for configuration of battery
    [hexmote_pcb.kicad_pcb, hexmote_pcb.kicad_sch]
2026-07-07 added BOM
    [BOM.csv, bom.csv, designators.csv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]
2026-07-08 changed somethings for case
    [BOM.csv, hexmote_pcb.kicad_pcb, hexmote_pcb.kicad_sch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]
2026-07-08 added finished CAD Files and rendered assets
    [Bottom Shell.step, Buttons.step, Full Assembly.step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]
2026-07-08 added 3d printer project for ease of use
    [3d print.3mf]
2026-07-08 Enhance README with images and project details
    Added images and additional details about the HexMote project, including CAD case design and BOM.
2026-07-08 fixed bom.csv
    [BOM.csv]
2026-07-08 added up to date gerber files
    [bom.csv]
2026-07-08 Modify quantities for specific BOM items
    Updated quantities for M3x5x4 Inserts and M3x6 screws in BOM.
    [BOM.csv]
2026-07-08 Adjust quantities for M3x5x4 Inserts and M3x6 screws
    Updated quantities for M3x5x4 Inserts and M3x6 screws in the parts list.
2026-07-08 Document PCB design process and CAD challenges
    Added detailed account of PCB design and CAD challenges, including images and reflections on the process.
2026-07-08 added switch hole and rendered it again
    [3d print.3mf, Bottom Shell.step, Buttons.step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]
2026-07-08 Update README with PCB link and schematic details
    Added a link to the PCB on KiCanvas and included information about the Gerbers and schematic improvements.
